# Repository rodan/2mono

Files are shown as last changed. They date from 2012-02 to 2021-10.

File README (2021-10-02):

small circuit that controls a APC SMART ups remotely via an Intertechno [1] relay. files are compatible with Eagle CAD 6.0+.

author:	 Petre Rodan <2b4eda@subdimension.ro>
version: rev1
license: GPLv3

the ups has two different buttons for power-on and off, and they need to be pushed at least a few seconds to activate. a single RF relay [1] will provide input to the board where edge triggering and two monostables and will control 2 small reed relays linked in parallel with the UPS buttons.

the board and the rf relay fit behind the plastic front pannel of the ups. see some pictures of the setup here [4].

tested with
 APC Smart-UPS 1000VA USB & Serial 230V (sku sua1000i) [2]
 APC Smart-UPS 1500VA USB & Serial 230V (sku sua1500i) [3]

[1] http://www.intertechno.at/produkte/empfaenger/schalter/CMR-1224.html
[2] http://www.apc.com/resource/include/techspec_index.cfm?base_sku=sua1000i
[3] http://www.apc.com/resource/include/techspec_index.cfm?base_sku=sua1500i
[4] https://photos.app.goo.gl/6eNyjTDTvezkR9XZ8

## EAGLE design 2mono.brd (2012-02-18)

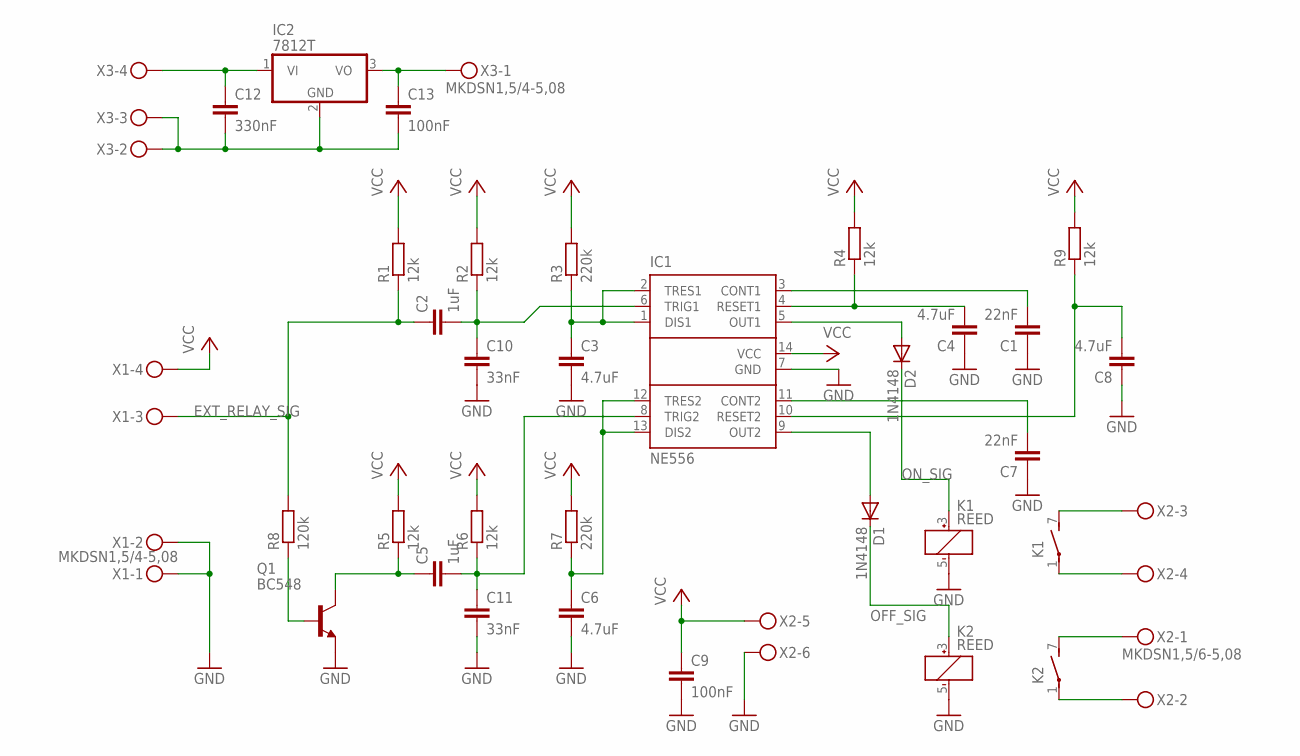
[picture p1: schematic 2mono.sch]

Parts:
C1, C7: 22nF; C050-025X075
C2, C5: 1uF; C025-030X050
C3, C4, C6, C8: 4.7uF; C025-030X050
C9, C13: 100nF; C075-042X103
C10, C11: 33nF; C050-030X075
C12: 330nF; C075-032X103
D1, D2: 1N4148; DO35-10
IC1: NE556; DIL14
IC2: 7812T; TO220H
K1, K2: REED
Q1: BC548; TO92-EBC
R1, R2, R4, R5, R6, R9: 12k; 0207/12
R3, R7: 220k; 0207/12
R8: 120k; 0207/12
X1, X3: MKDSN1,5/4-5,08
X2: MKDSN1,5/6-5,08

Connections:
EXT_RELAY_SIG: C2.1, R1.1, R8.2, X1.3
GND: C1.1, C3.2, C4.1, C6.2, C7.1, C8.1, C9.2, C10.2, C11.2, IC1.7 (GND), K1.5 (-), K2.5 (-), Q1.E, X1.1, X1.2, X2.6
unnamed: C3.1, IC1.1 (DIS1), IC1.2 (TRES1), R3.1
unnamed: C2.2, C10.1, IC1.6 (TRIG1), R2.1
unnamed: C6.1, IC1.12 (TRES2), IC1.13 (DIS2), R7.1
unnamed: C1.2, IC1.3 (CONT1)
unnamed: C4.2, IC1.4 (RESET1), R4.1
unnamed: C5.1, Q1.C, R5.1
unnamed: Q1.B, R8.1
unnamed: C5.2, C11.1, IC1.8 (TRIG2), R6.1
unnamed: C7.2, IC1.11 (CONT2)
unnamed: C8.2, IC1.10 (RESET2), R9.1
unnamed: D2.A, IC1.5 (OUT1)
unnamed: K2.7 (S), X2.1
unnamed: K2.1, X2.2
unnamed: K1.1, X2.4
unnamed: D1.A, IC1.9 (OUT2)
unnamed: C12.1, IC2.1 (VI), X3.4
unnamed: K1.7 (S), X2.3
unnamed: C13.1, IC2.3 (VO), X3.1
unnamed: C12.2, C13.2, IC2.2 (GND), X3.2, X3.3
OFF_SIG: D1.C, K2.3 (+)
ON_SIG: D2.C, K1.3 (+)
VCC: C9.1, IC1.14 (VCC), R1.2, R2.2, R3.2, R4.2, R5.2, R6.2, R7.2, R9.2, X1.4, X2.5

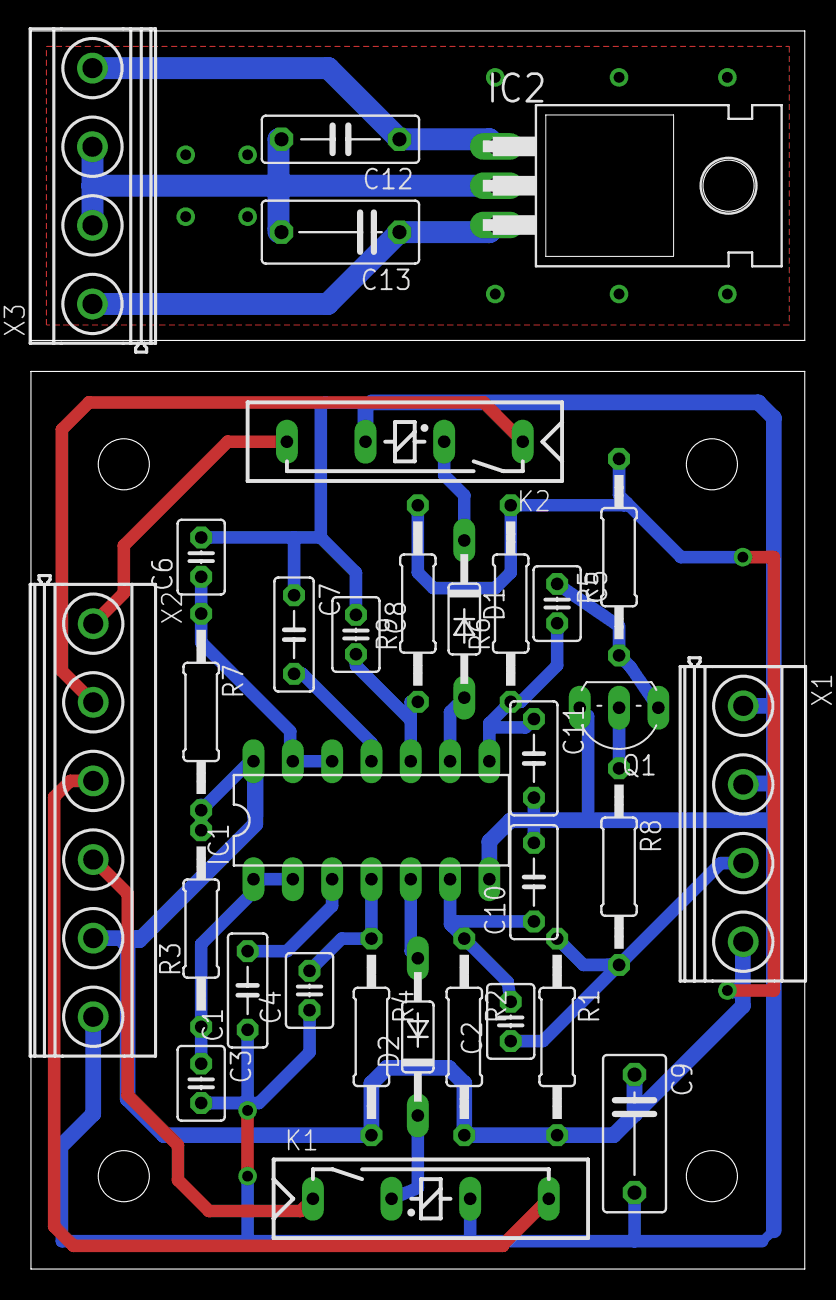
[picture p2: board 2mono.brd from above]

Board: 2 copper layers, 50.0 x 80.0 mm, 32 parts (0 on the bottom side), 24 nets.
